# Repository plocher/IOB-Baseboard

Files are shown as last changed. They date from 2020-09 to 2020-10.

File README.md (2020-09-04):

# IOB-Baseboard
## License: CERN Open Hardware Licence v1.2

IOB Baseboard - wiring termination and I2C / Power bus management

The latest in the evolution of the perfect layout I/O system...
Previous I2C-xxx designs either let to a proliferation of adapters
(current sink, input filters...) and to less than robust mechanical
designs (daughtercards that easily pulled out of their sockets with
cable movement)

This version does 4 things:
 * All wiring is terminated into mechanically stable connection points
 * There are personality adapters to account for the level shifting, buffering and other I/O line adaptions that may be needed
 * While I like having blinking LED lights on every I/O line for debugging, others do not - so there is now a plug-in LED monitor slot for each set of 4x I/O lines
 * A generic I2C Expander plug in footprint.

I have built several board variations for various different I2C
Expander chips to take advantage of unique addressing, I/O levels,
cost, etc - with the only thing changing between boards being the
chip related stuff.  Maintaining and stocking several "slightly
different" board designs gets expensive, both from both inventory
and support perspectives.

V1.0 is a prototype that seeks to validate the basic modular assumptions I'm making.

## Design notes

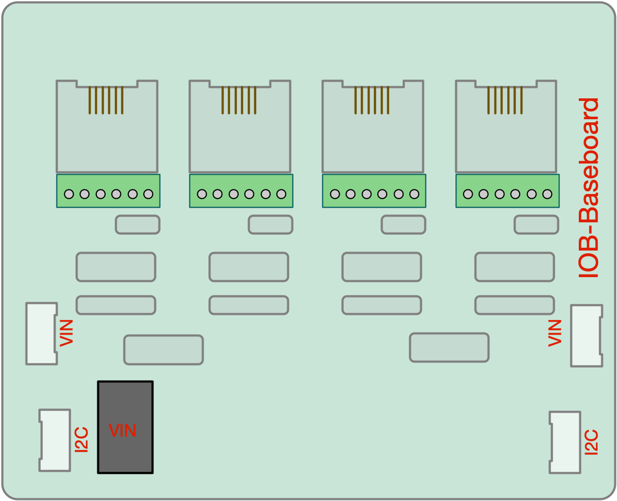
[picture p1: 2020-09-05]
IOB-Baseboard-Graphic.png

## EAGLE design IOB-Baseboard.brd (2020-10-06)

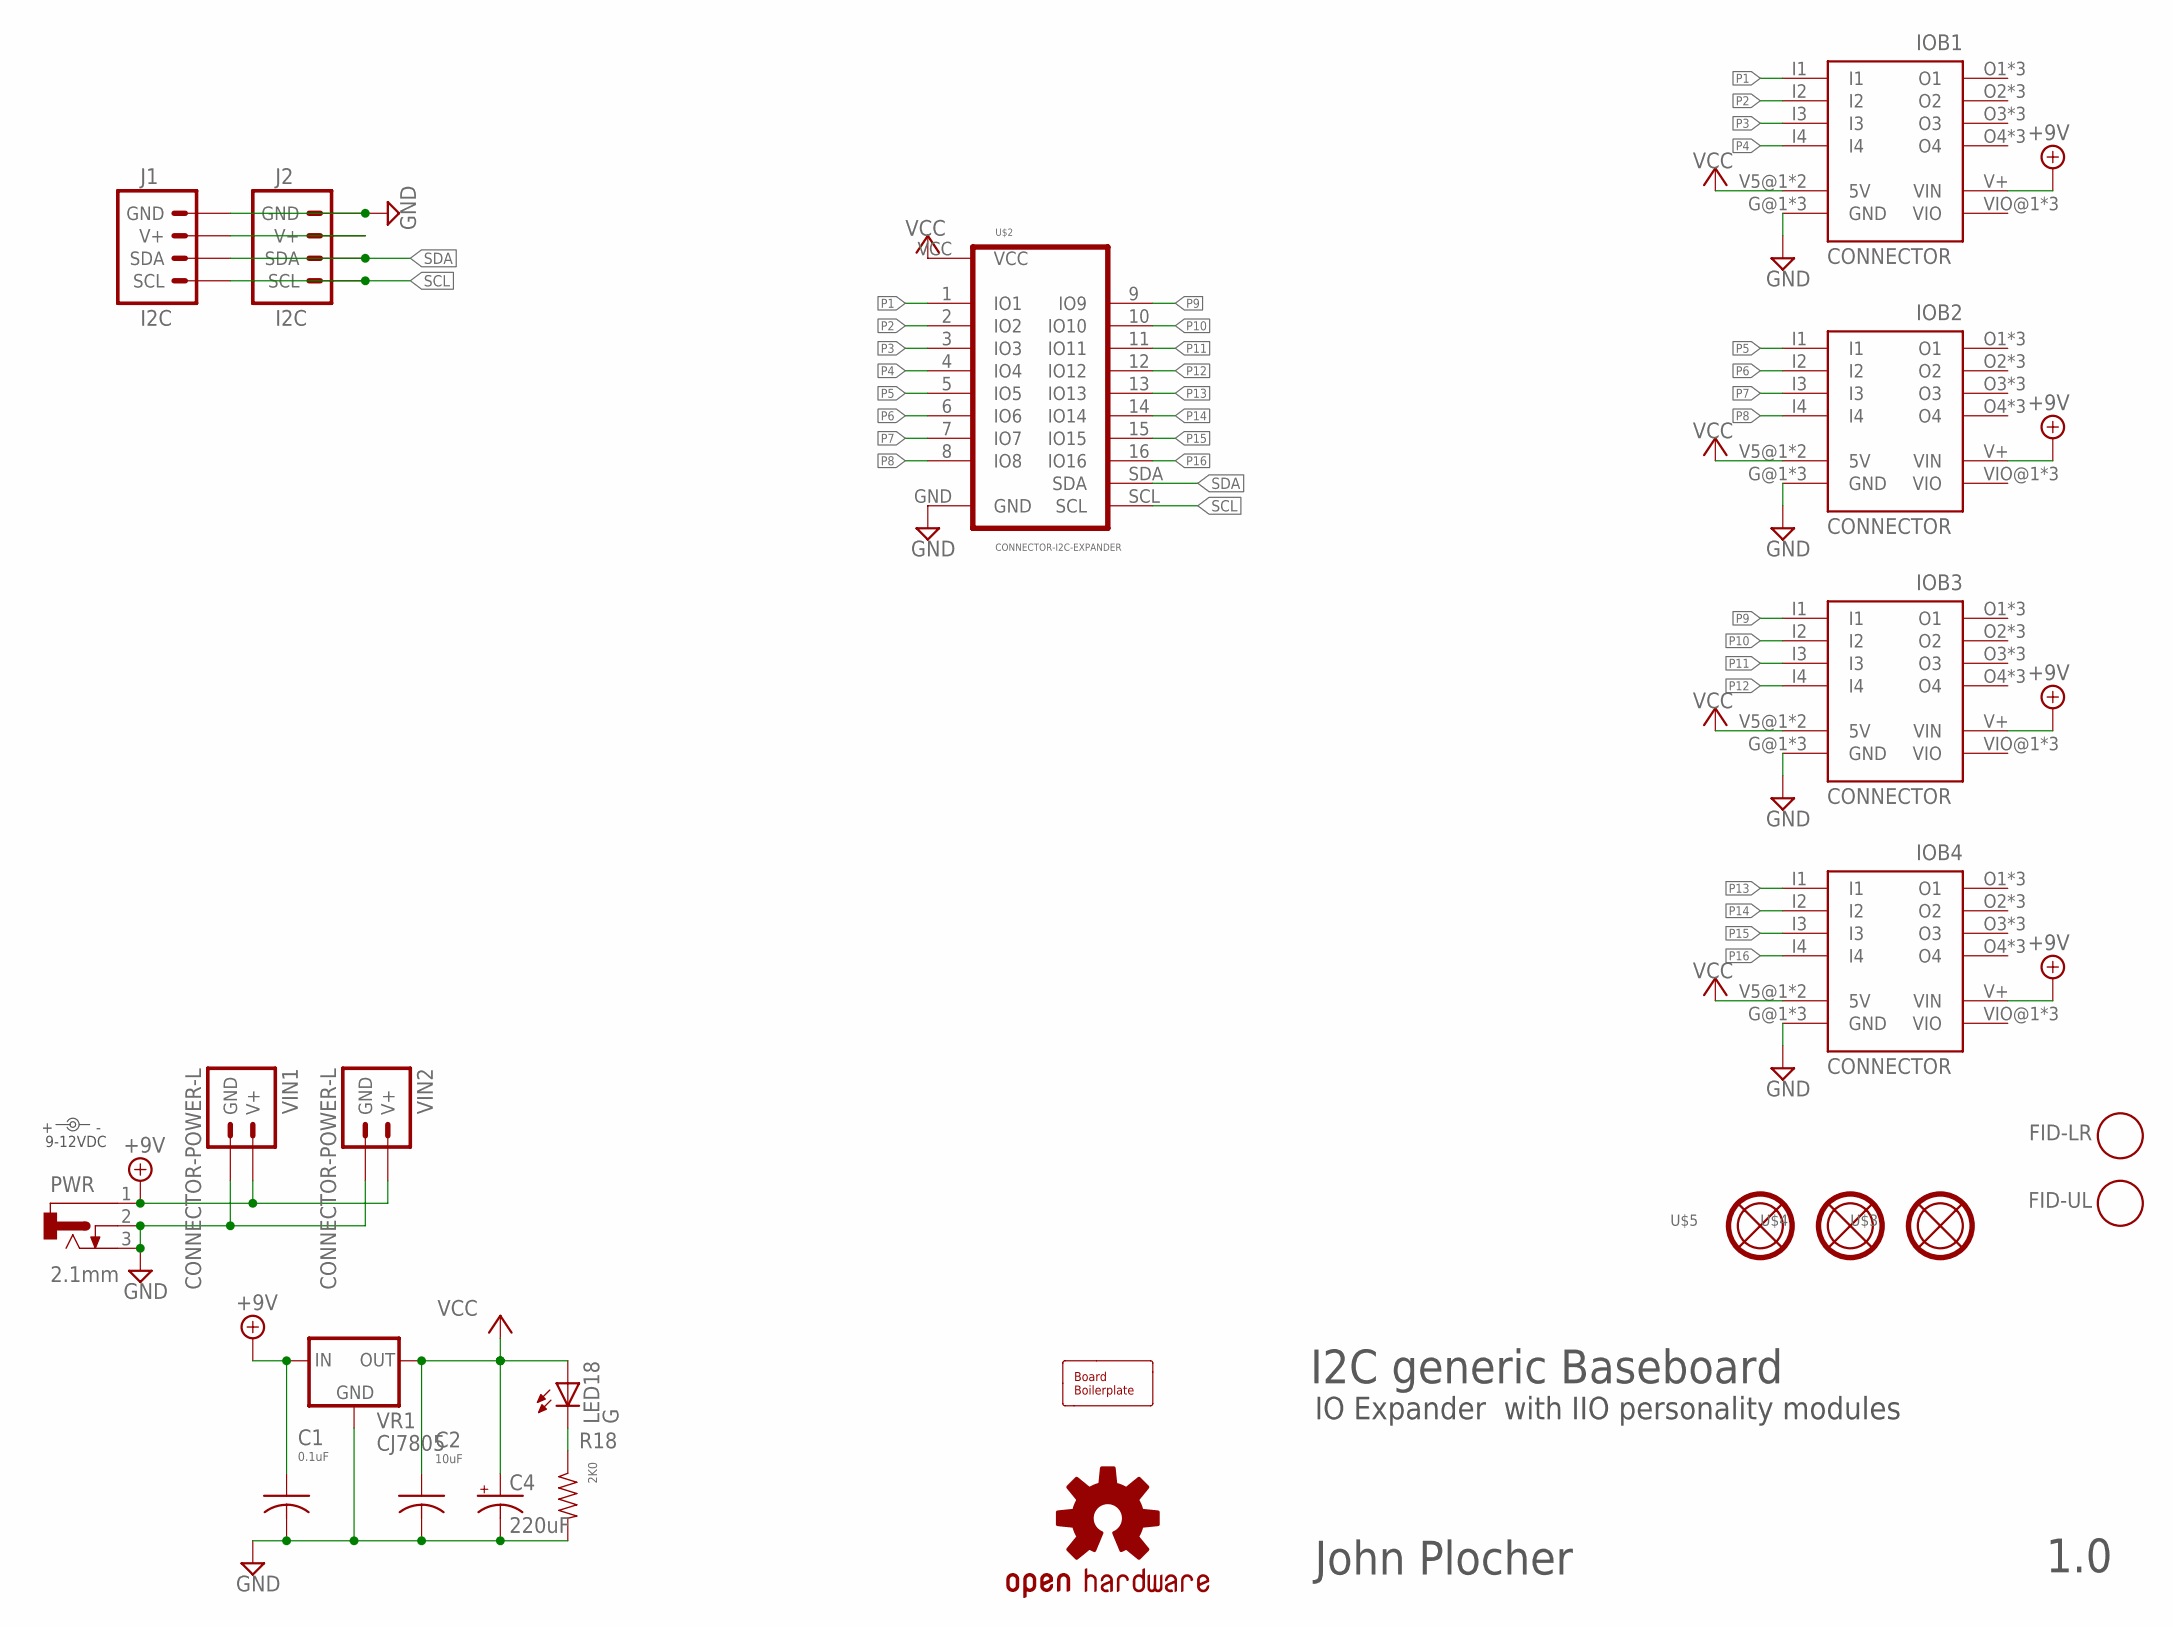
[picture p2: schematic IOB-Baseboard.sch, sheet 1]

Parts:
BOARD1: BOARD; BOARD-DINRAIL-3.17IN-IOB
C1: 0.1uF; 0603-CAP
C2: 10uF; 0603-CAP
C4: 220uF; 0810-CAP
FID-LR: FIDUCIAL; FIDUCIAL_1MM
FID-UL: FIDUCIAL; FIDUCIAL_1MM
IOB1, IOB2, IOB3, IOB4: CONNECTOR; IOB-V3-BASE
J1, J2: I2C; I2C-L
LED18: G; 0603-LED
PWR: 2.1mm; DCJ0202
R18: 2K0; 0603-RES
U$1: OSHW; OSHW-LOGO-L
U$2: CONNECTOR-I2C-EXPANDER; I2C-EXPANDER
U$3, U$4, U$5: MOUNTINGHOLE
VIN: 9-12VDC; PWR_LABEL
VIN1, VIN2: CONNECTOR-POWER-L; POWER-R2
VR1: CJ7805; TO-252

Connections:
GND: C1.2, C2.2, C4.-, IOB1.G@1 (GND), IOB1.G@2 (GND), IOB1.GND@3 (GND), IOB2.G@1 (GND), IOB2.G@2 (GND), IOB2.GND@3 (GND), IOB3.G@1 (GND), IOB3.G@2 (GND), IOB3.GND@3 (GND), IOB4.G@1 (GND), IOB4.G@2 (GND), IOB4.GND@3 (GND), J1.GND, J1.GND@1 (GND), J2.GND, J2.GND@1 (GND), PWR.2, PWR.3, R18.2, U$2.GND, VIN1.GND, VIN1.GND@1 (GND), VIN1.GND@2 (GND), VIN1.GND@3 (GND), VIN2.GND, VIN2.GND@1 (GND), VIN2.GND@2 (GND), VIN2.GND@3 (GND), VR1.2 (GND); also elsewhere on the board
unnamed: LED18.C, R18.1
P1: IOB1.I1, U$2.1 (IO1); also elsewhere on the board
P2: IOB1.I2, U$2.2 (IO2); also elsewhere on the board
P3: IOB1.I3, U$2.3 (IO3); also elsewhere on the board
P4: IOB1.I4, U$2.4 (IO4); also elsewhere on the board
P5: IOB2.I1, U$2.5 (IO5); also elsewhere on the board
P6: IOB2.I2, U$2.6 (IO6); also elsewhere on the board
P7: IOB2.I3, U$2.7 (IO7); also elsewhere on the board
P8: IOB2.I4, U$2.8 (IO8); also elsewhere on the board
P9: IOB3.I1, U$2.9 (IO9); also elsewhere on the board
P10: IOB3.I2, U$2.10 (IO10); also elsewhere on the board
P11: IOB3.I3, U$2.11 (IO11); also elsewhere on the board
P12: IOB3.I4, U$2.12 (IO12); also elsewhere on the board
P13: IOB4.I1, U$2.13 (IO13); also elsewhere on the board
P14: IOB4.I2, U$2.14 (IO14); also elsewhere on the board
P15: IOB4.I3, U$2.15 (IO15); also elsewhere on the board
P16: IOB4.I4, U$2.16 (IO16); also elsewhere on the board
SCL: J1.SCL, J1.SCL@1 (SCL), J2.SCL, J2.SCL@1 (SCL), U$2.SCL
SDA: J1.SDA, J1.SDA@1 (SDA), J2.SDA, J2.SDA@1 (SDA), U$2.SDA
V+I2C: J1.V+, J1.V+@1 (V+), J2.V+, J2.V+@1 (V+)
VCC: C2.1, C4.+, IOB1.V5@1 (5V), IOB1.V5@2 (5V), IOB2.V5@1 (5V), IOB2.V5@2 (5V), IOB3.V5@1 (5V), IOB3.V5@2 (5V), IOB4.V5@1 (5V), IOB4.V5@2 (5V), LED18.A, U$2.VCC, VR1.3 (OUT); also elsewhere on the board
VIN: C1.1, IOB1.V+ (VIN), IOB2.V+ (VIN), IOB3.V+ (VIN), IOB4.V+ (VIN), PWR.1, VIN1.V+, VIN1.V+@1 (V+), VIN1.V+@2 (V+), VIN1.V+@3 (V+), VIN2.V+, VIN2.V+@1 (V+), VIN2.V+@2 (V+), VIN2.V+@3 (V+), VR1.1 (IN)

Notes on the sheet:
I2C generic Baseboard
IO Expander with IIO personality modules
John Plocher
1.0

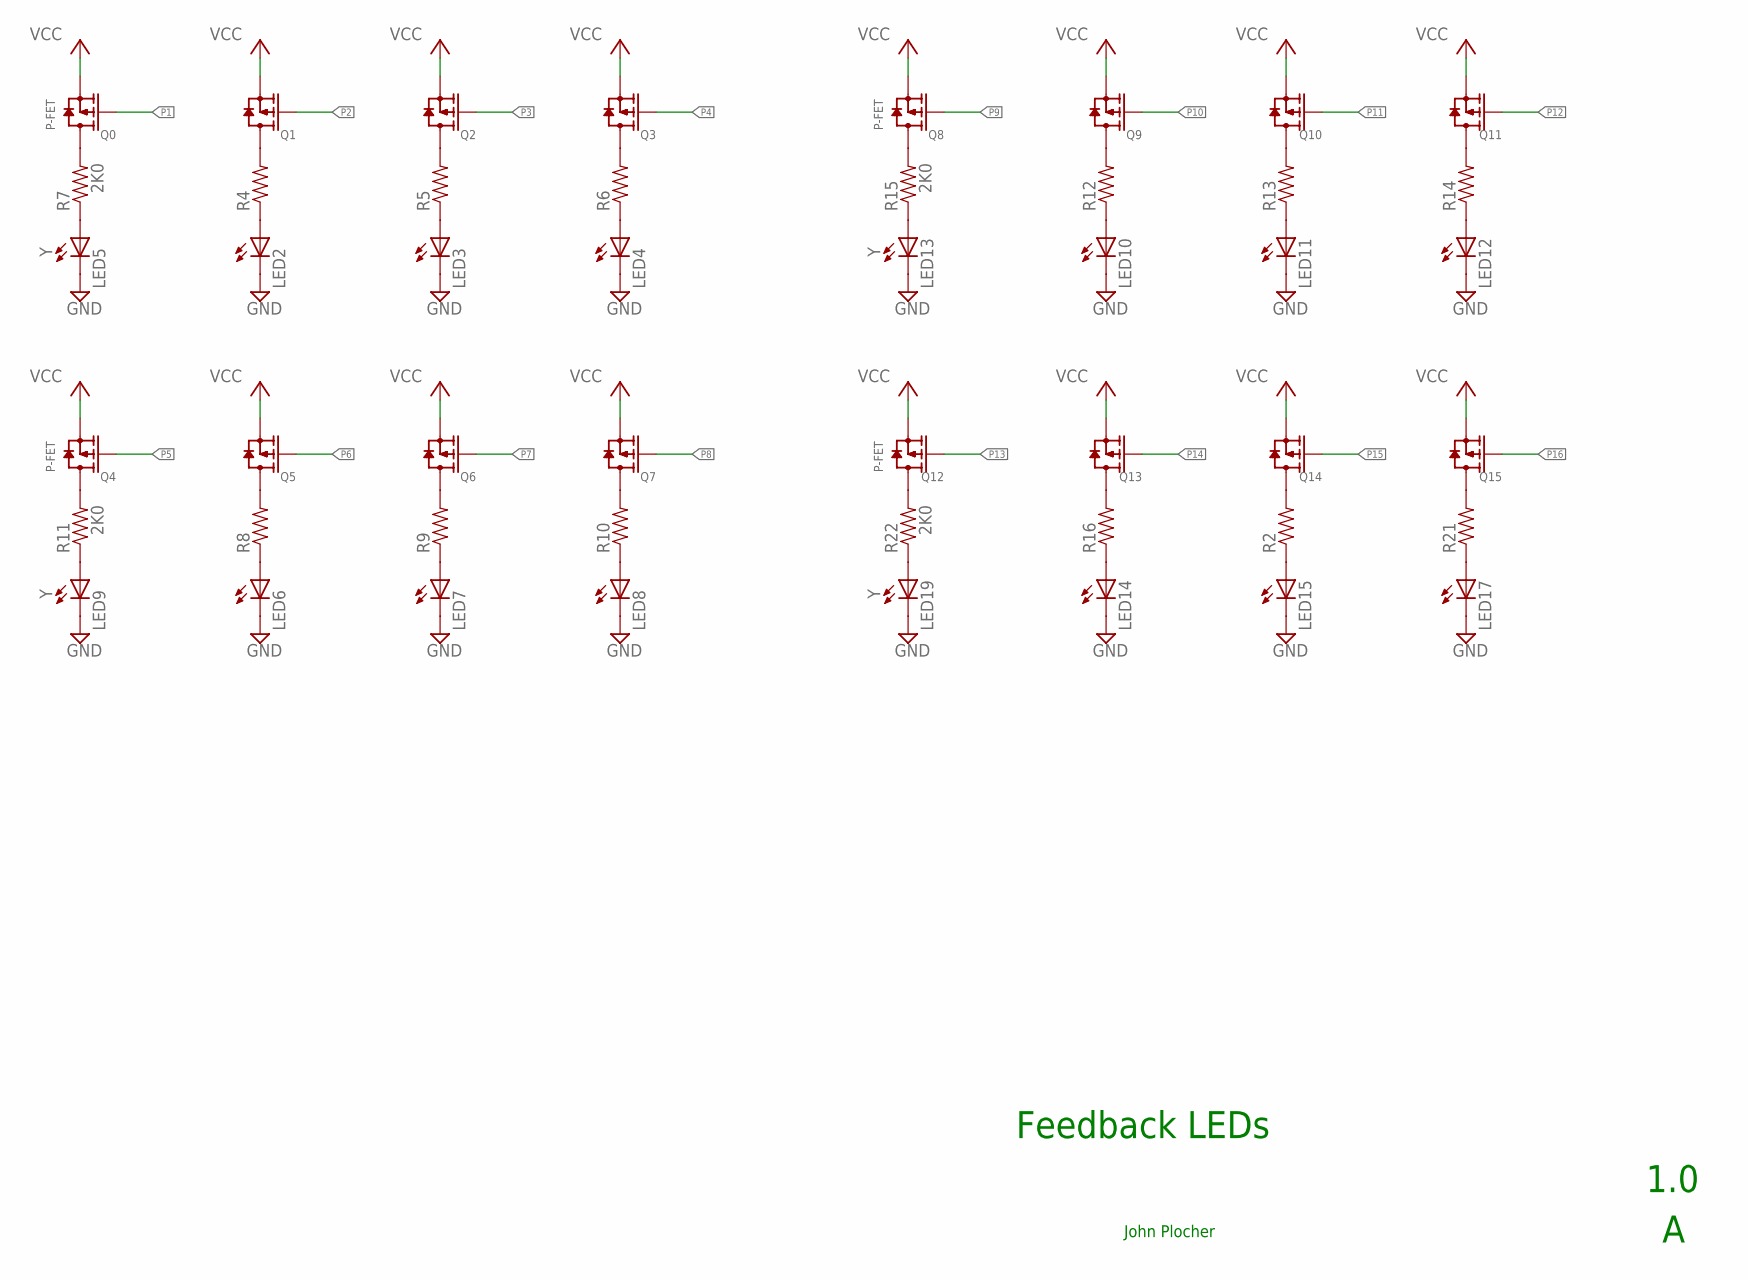
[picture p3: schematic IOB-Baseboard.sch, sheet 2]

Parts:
LED2, LED3, LED4, LED5, LED6, LED7, LED8, LED9, LED10, LED11, LED12, LED13, LED14, LED15, LED17, LED19: Y; 0603-LED
Q0, Q1, Q2, Q3, Q4, Q5, Q6, Q7, Q8, Q9, Q10, Q11, Q12, Q13, Q14, Q15: P-FET; SOT23
R2, R4, R5, R6, R7, R8, R9, R10, R11, R12, R13, R14, R15, R16, R21, R22: 2K0; 0603-RES

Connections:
GND: LED2.C, LED3.C, LED4.C, LED5.C, LED6.C, LED7.C, LED8.C, LED9.C, LED10.C, LED11.C, LED12.C, LED13.C, LED14.C, LED15.C, LED17.C, LED19.C; also elsewhere on the board
unnamed: Q4.3 (D), R11.2
unnamed: Q5.3 (D), R8.2
unnamed: Q6.3 (D), R9.2
unnamed: Q7.3 (D), R10.2
unnamed: LED9.A, R11.1
unnamed: LED6.A, R8.1
unnamed: LED7.A, R9.1
unnamed: LED8.A, R10.1
unnamed: Q8.3 (D), R15.2
unnamed: Q9.3 (D), R12.2
unnamed: Q10.3 (D), R13.2
unnamed: Q11.3 (D), R14.2
unnamed: LED13.A, R15.1
unnamed: LED10.A, R12.1
unnamed: LED11.A, R13.1
unnamed: LED12.A, R14.1
unnamed: Q12.3 (D), R22.2
unnamed: Q13.3 (D), R16.2
unnamed: Q14.3 (D), R2.2
unnamed: Q15.3 (D), R21.2
unnamed: LED19.A, R22.1
unnamed: LED14.A, R16.1
unnamed: LED15.A, R2.1
unnamed: LED17.A, R21.1
unnamed: Q0.3 (D), R7.2
unnamed: Q1.3 (D), R4.2
unnamed: Q2.3 (D), R5.2
unnamed: Q3.3 (D), R6.2
unnamed: LED5.A, R7.1
unnamed: LED2.A, R4.1
unnamed: LED3.A, R5.1
unnamed: LED4.A, R6.1
P1: Q0.1 (G); also elsewhere on the board
P2: Q1.1 (G); also elsewhere on the board
P3: Q2.1 (G); also elsewhere on the board
P4: Q3.1 (G); also elsewhere on the board
P5: Q4.1 (G); also elsewhere on the board
P6: Q5.1 (G); also elsewhere on the board
P7: Q6.1 (G); also elsewhere on the board
P8: Q7.1 (G); also elsewhere on the board
P9: Q8.1 (G); also elsewhere on the board
P10: Q9.1 (G); also elsewhere on the board
P11: Q10.1 (G); also elsewhere on the board
P12: Q11.1 (G); also elsewhere on the board
P13: Q12.1 (G); also elsewhere on the board
P14: Q13.1 (G); also elsewhere on the board
P15: Q14.1 (G); also elsewhere on the board
P16: Q15.1 (G); also elsewhere on the board
VCC: Q0.2 (S), Q1.2 (S), Q2.2 (S), Q3.2 (S), Q4.2 (S), Q5.2 (S), Q6.2 (S), Q7.2 (S), Q8.2 (S), Q9.2 (S), Q10.2 (S), Q11.2 (S), Q12.2 (S), Q13.2 (S), Q14.2 (S), Q15.2 (S); also elsewhere on the board

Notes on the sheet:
Feedback LEDs
1.0
John Plocher

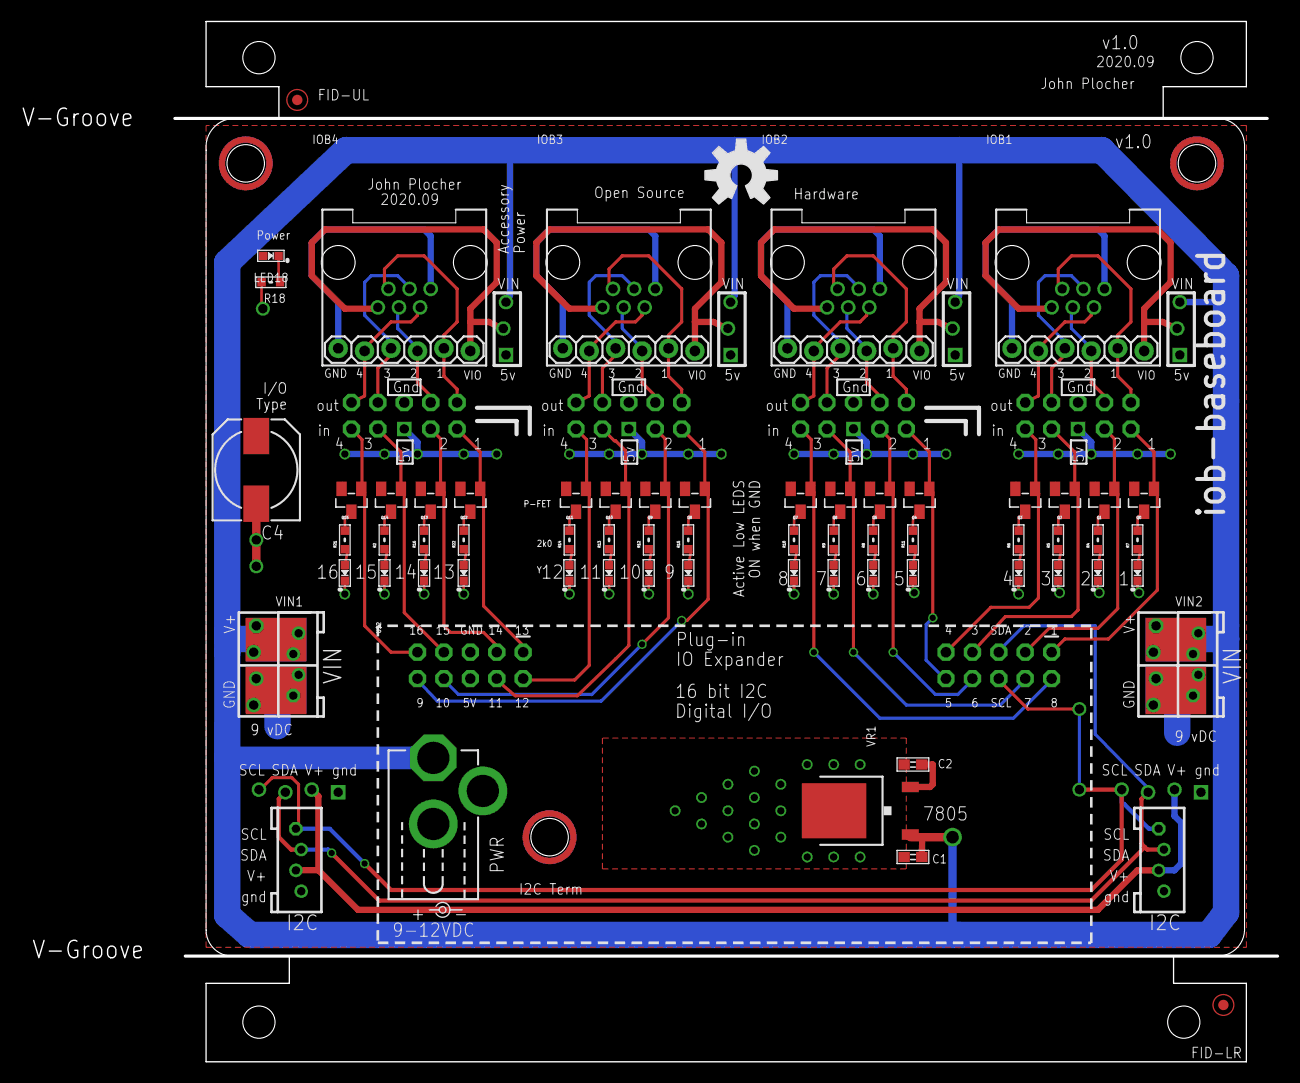
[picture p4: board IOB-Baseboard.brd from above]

Board: 2 copper layers, 106.0 x 100.0 mm, 72 parts (0 on the bottom side), 55 nets.

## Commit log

2020-09-04 Initial version
    [IOB-Baseboard.brd, IOB-Baseboard.sch]
2020-09-05 fixed silk, added graphic
    [IOB-Baseboard.brd]
2020-09-05 added mounting holes
    [IOB-Baseboard.brd, IOB-Baseboard.sch]
2020-09-11 put LEDS back on board, move 2x5 personal;ity and VIO connectors
    [IOB-Baseboard.brd, IOB-Baseboard.sch]
2020-09-11 update version text
    [IOB-Baseboard.brd, IOB-Baseboard.sch]
2020-10-05 added values for connectors
    [IOB-Baseboard.brd, IOB-Baseboard.sch]
2020-10-06 normalized values
    [IOB-Baseboard.brd, IOB-Baseboard.sch]
